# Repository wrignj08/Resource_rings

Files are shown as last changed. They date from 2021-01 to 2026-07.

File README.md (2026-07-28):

# Resource_rings
This was a weekend project to display my computers (Ubuntu 20.04) CPU, RAM and GPU (NVIDIA) utilisation and temps on an external display, all the code and design files are available.
The project is powered by a Teensy 4.0 and uses four Addressable LED Ring - 16 Bit WS2812 RGB LED modules.
The display is designed to be mounted on the underside of a KOGAN 34" WQHD CURVED 21:9 ULTRAWIDE monitor.

You can check out the design and download the CAD at the link below
https://cad.onshape.com/documents/9b6b9370298a401bef62185d/w/3fc23328799e8dd97975f60a/e/fd6b8e9bd227a1a2b682e71e

The code on the Teensy is an Arduino sketch, the code on the PC is Python.

The Python side is managed with [uv](https://docs.astral.sh/uv/). Run `uv sync` to create the venv, then `./Run_rings.sh` to start the sender.

<p align="center">
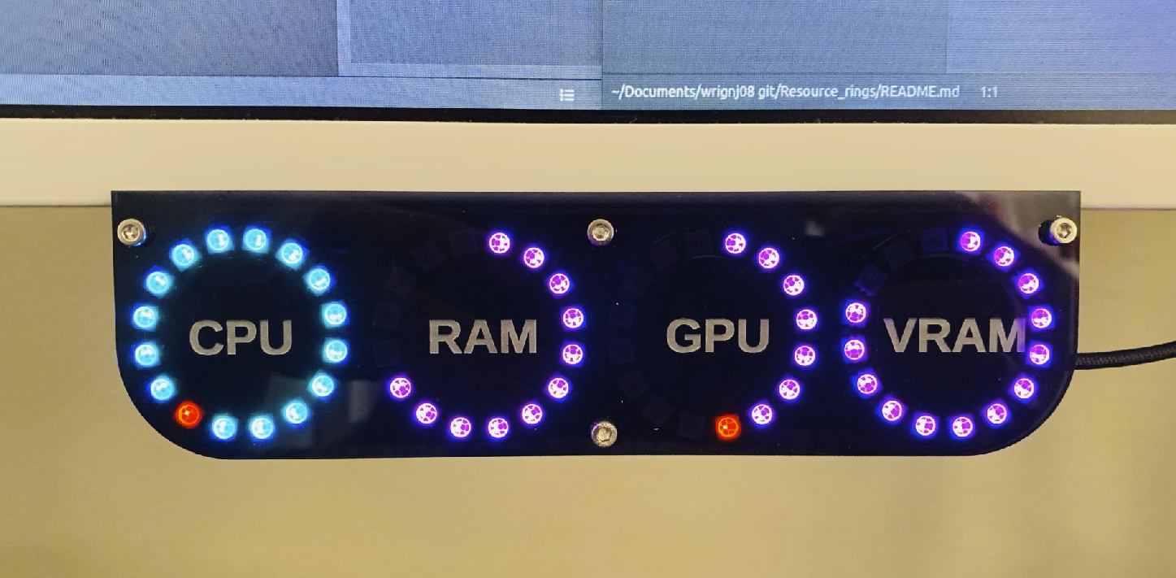
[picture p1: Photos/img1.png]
  
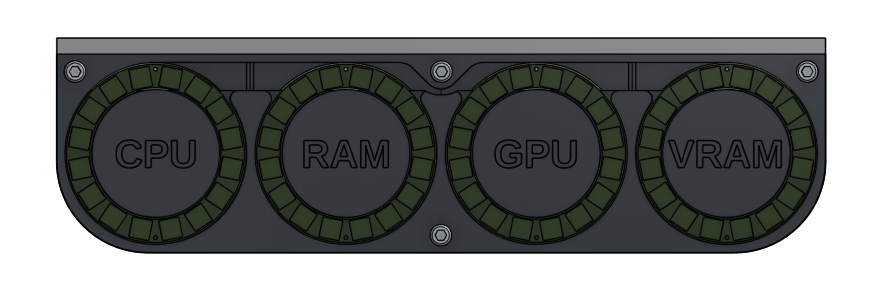
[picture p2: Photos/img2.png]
  
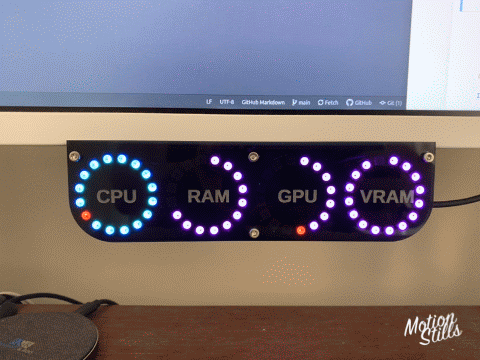
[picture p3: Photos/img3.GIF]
  
</p>

Features:<br>
CPU usage max core, purple on dial 1<br>
CPU usage max core last reading, green on dial 1<br>
CPU usage all core mean, teal on dial 1 overprints max core<br>
CPU temp, red on dial 1<br>
RAM usage, purple on dial 2<br>
RAM usage last reading, green on dial 2<br>
GPU usage, purple on dial 3<br>
GPU usage last reading, green on dial 3<br>
GPU temp, red on dial 3<br>
VRAM usage, purple on dial 4<br>
VRAM usage last reading, green dial 4<br>

Hardware:<br>
1 x Teensy 4.0 (probibly overkill but does a good job)<br>
https://core-electronics.com.au/teensy-4-0.html<br>
4 x Addressable LED Ring - 16 Bit WS2812 RGB LED<br>
https://core-electronics.com.au/cjmcu-16-bit-ws2812-5050-rgb-led-built-in-full-color-driving-lights-circle-development-board.html<br>
6 x M3 stainless steel self tapping thread insert<br>
https://www.aliexpress.com/item/32889542737.html<br>
6 x M3 x 8mm bolts<br>
https://www.aliexpress.com/item/1005001975621423.html<br>
3D printed housing (3 files, PLA is fine)<br>
https://github.com/wrignj08/Resource_rings/tree/main/CAD/3D%20printed%20STL%20files<br>
Laser cut and engraved acrylic face plate<br>
https://github.com/wrignj08/Resource_rings/tree/main/CAD/Later%20cut%20acrylic<br>

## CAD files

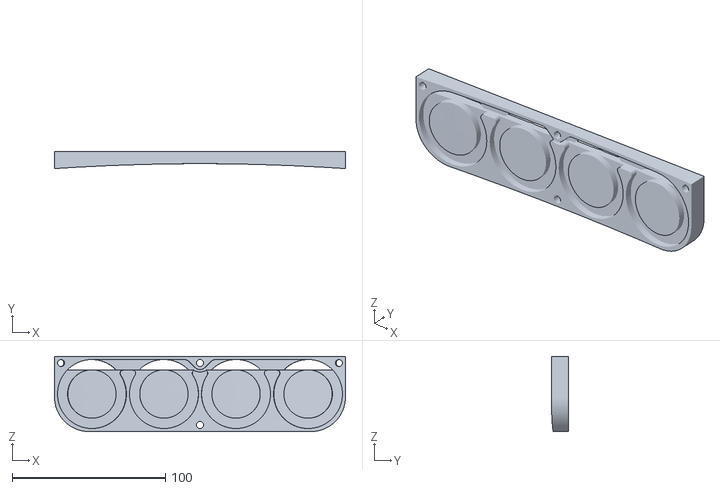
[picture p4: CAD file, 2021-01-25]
CAD/3D printed STL files/Monitor housing - Part 3.stl
189.9 x 11.2 x 49.0

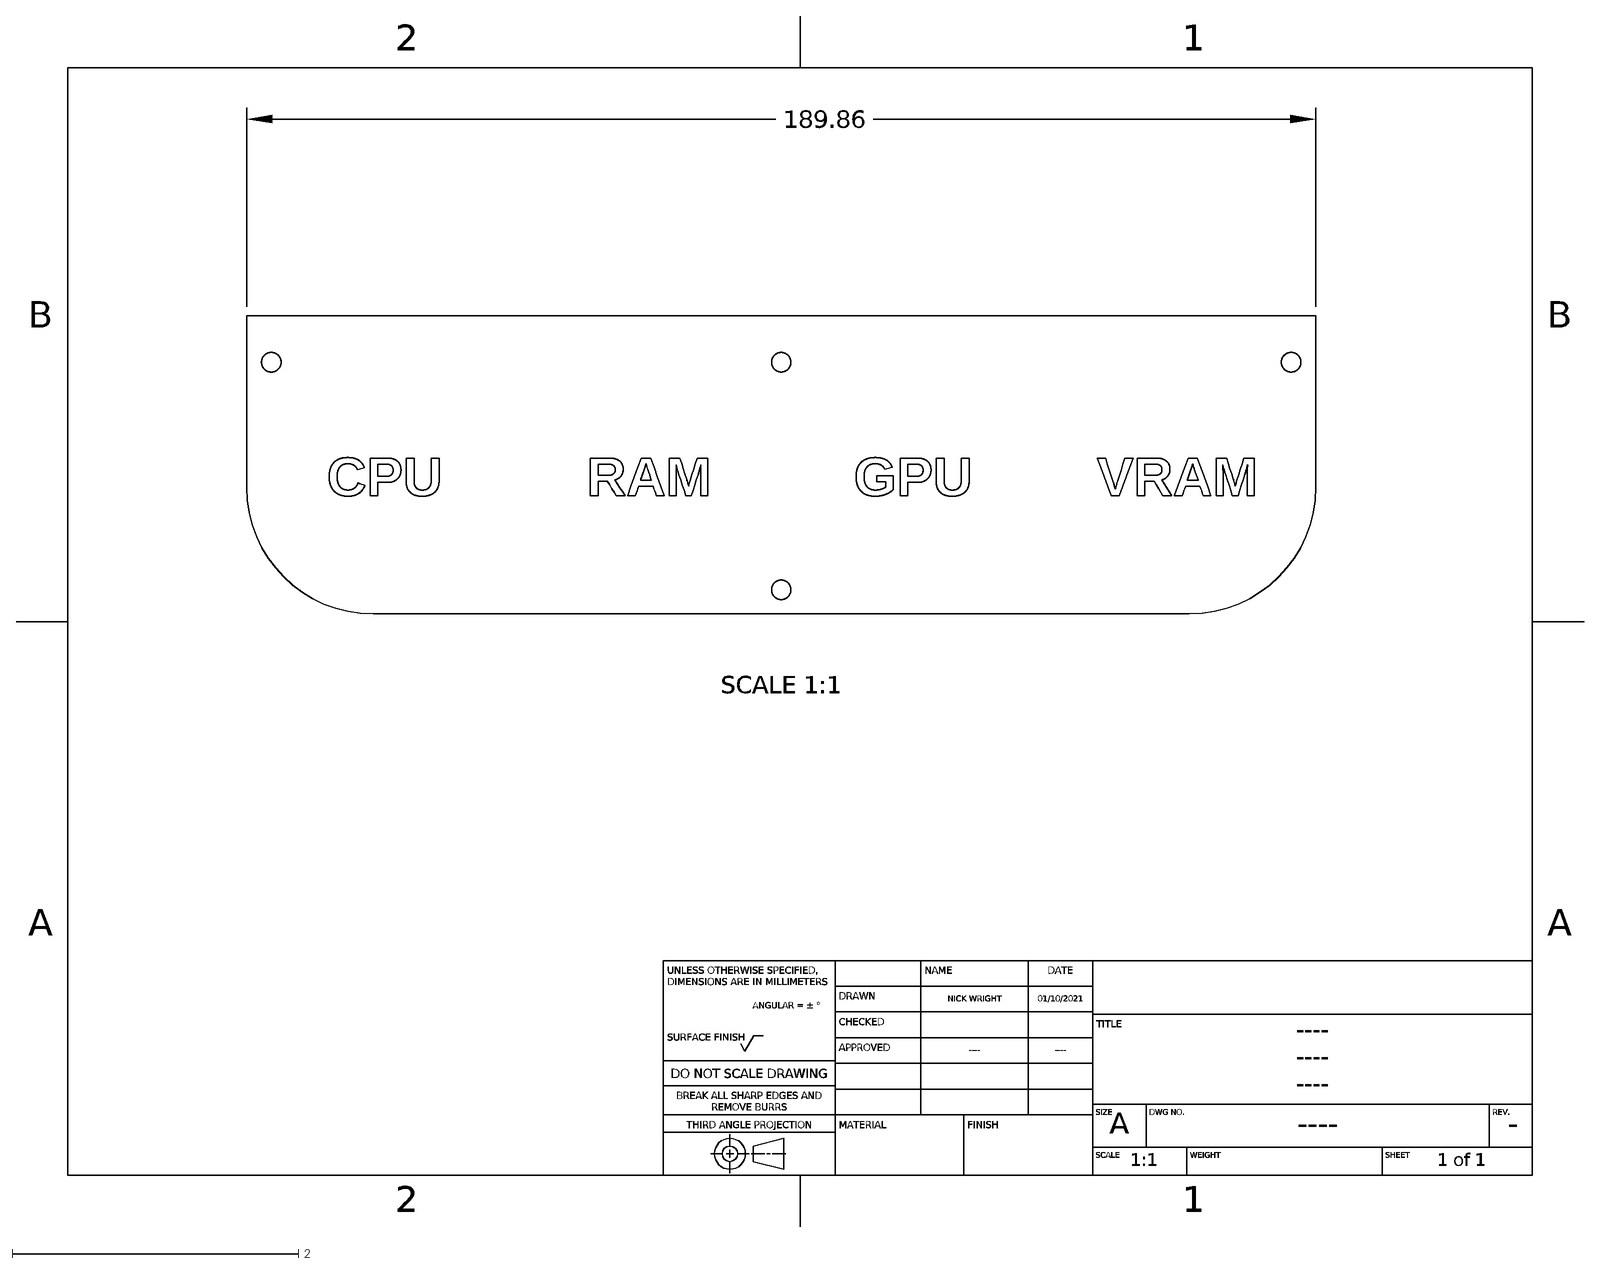
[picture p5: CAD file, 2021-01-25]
CAD/Later cut acrylic/Sketch 11 Drawing 1.dxf
2
1
A
B
UNLESS OTHERWISE SPECIFIED, DIMENSIONS ARE IN MILLIMETERS
ANGULAR = ± °
SURFACE FINISH
DO NOT SCALE DRAWING
BREAK ALL SHARP EDGES AND REMOVE BURRS
THIRD ANGLE PROJECTION
NAME
DATE
DRAWN
NICK WRIGHT
01/10/2021
CHECKED
APPROVED
----
MATERIAL
FINISH
TITLE
SIZE
DWG NO.
REV.
-
SCALE
1:1
WEIGHT
SHEET
1 of 1
SCALE 1:1
189.86

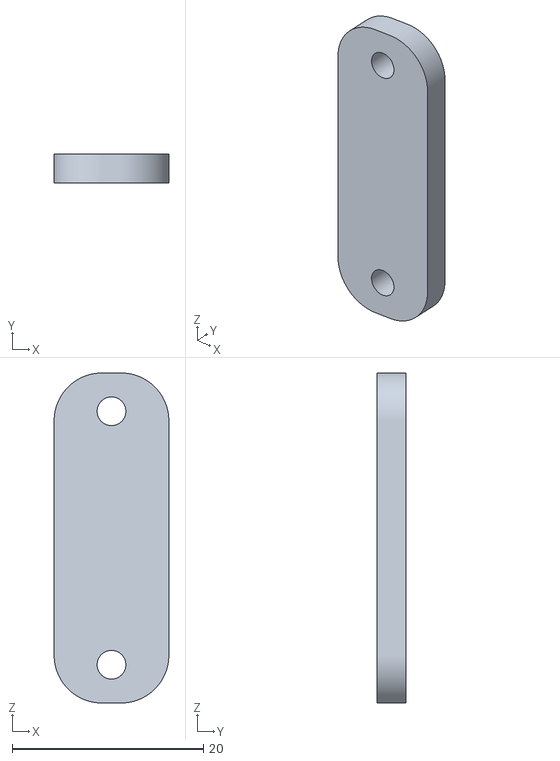
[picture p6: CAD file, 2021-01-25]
CAD/3D printed STL files/Monitor housing - Part 1.stl
12.0 x 3.00 x 34.5

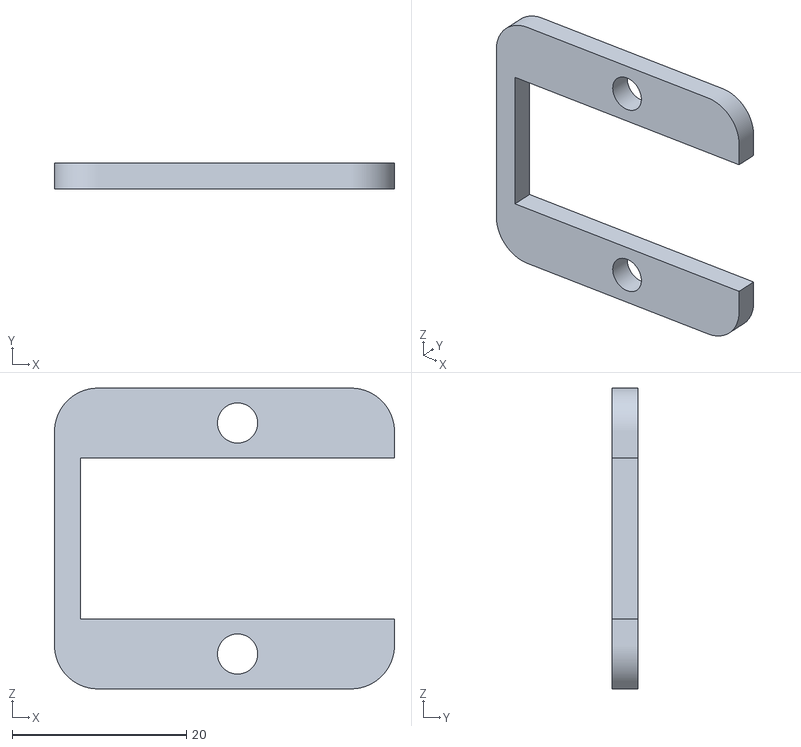
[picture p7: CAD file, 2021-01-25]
CAD/3D printed STL files/Monitor housing - Part 4.stl
39.0 x 3.00 x 34.5

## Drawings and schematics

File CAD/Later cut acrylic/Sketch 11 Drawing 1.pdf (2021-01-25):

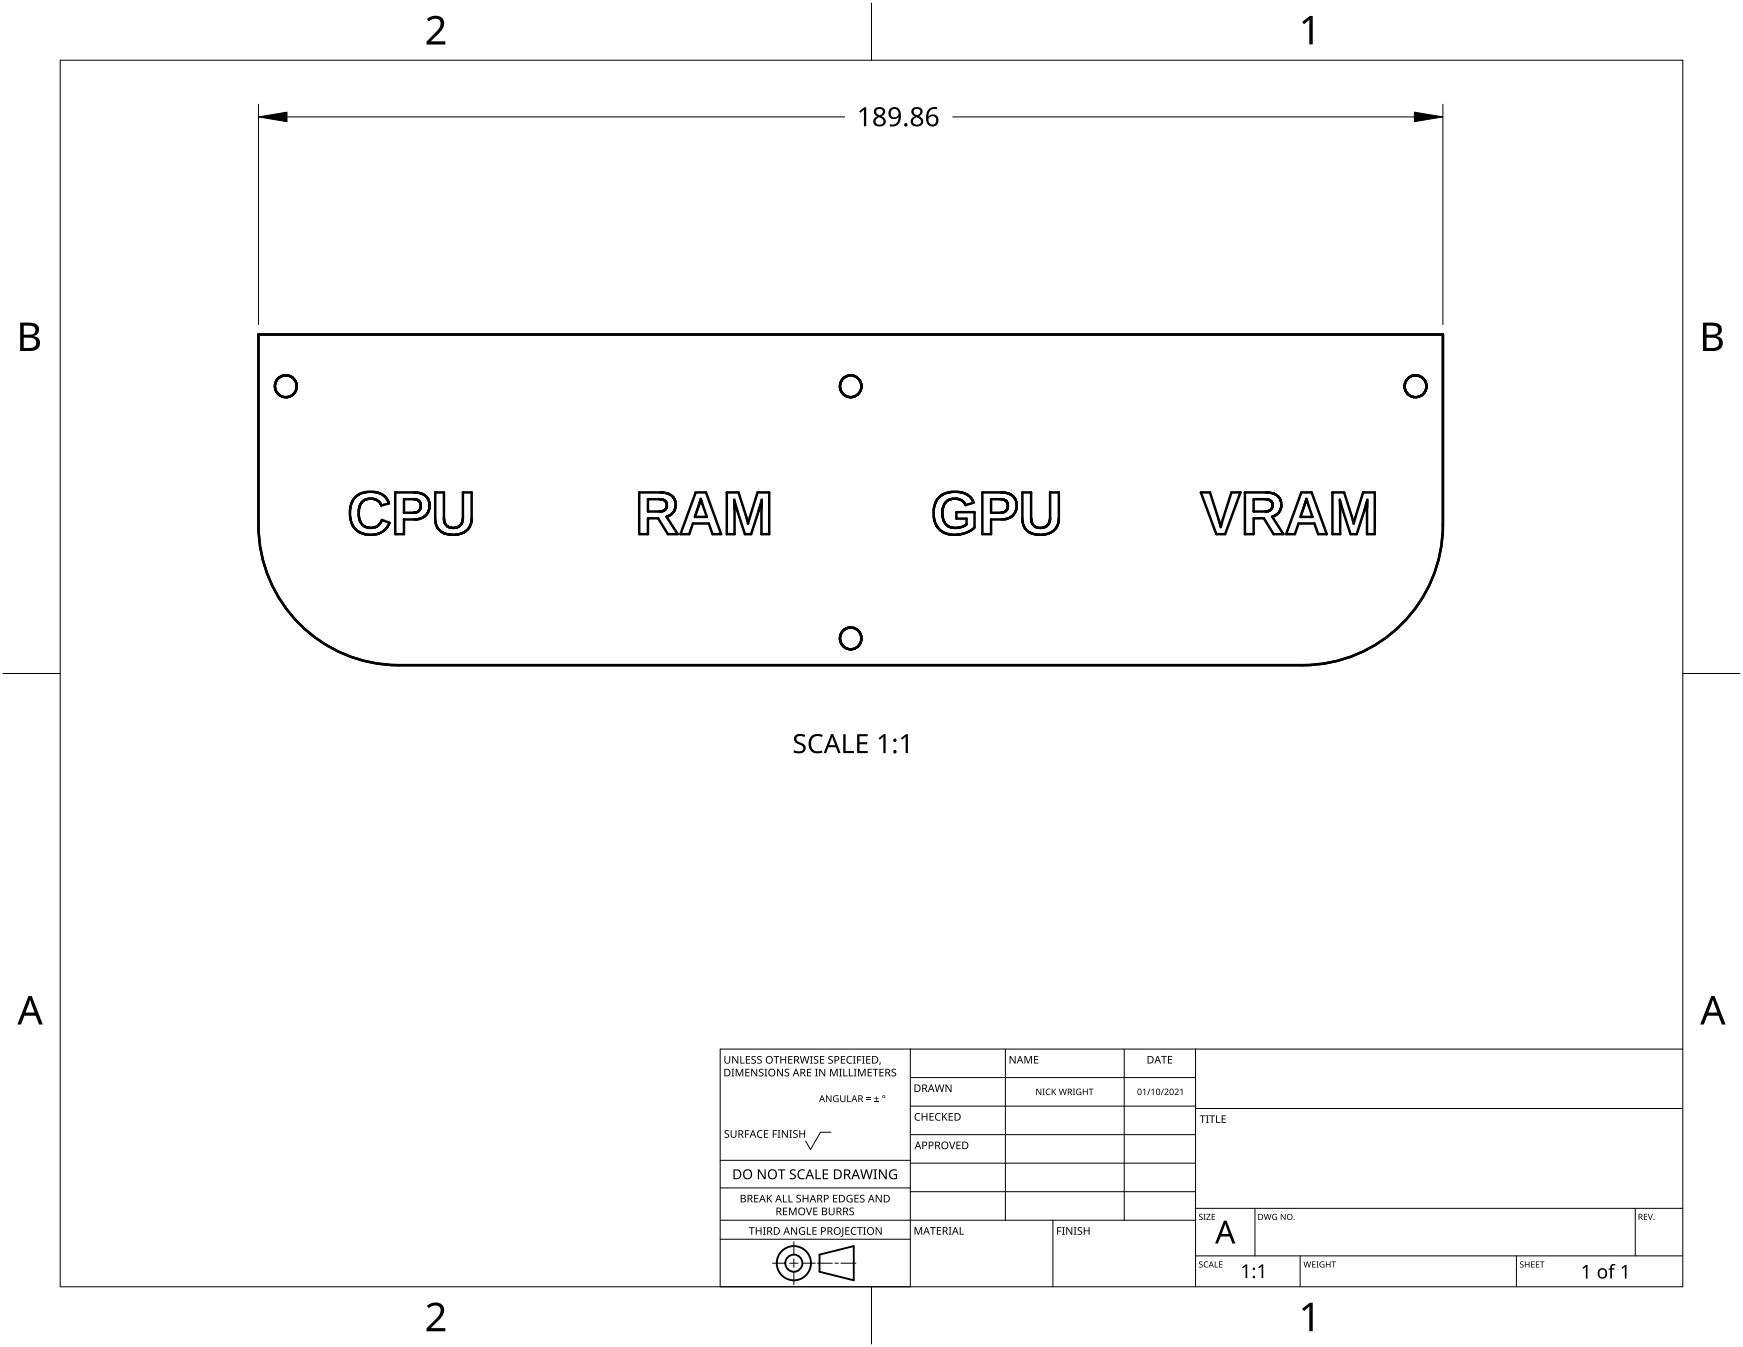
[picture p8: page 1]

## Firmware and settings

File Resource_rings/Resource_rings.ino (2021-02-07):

#include <FastLED.h>
#define NUM_LEDS_PER_STRIP 64
#define DATA_PIN 10
#define NUM_STRIPS 1
CRGB leds[NUM_LEDS_PER_STRIP * NUM_STRIPS];

const byte numChars = 32;
char receivedChars[numChars];
char tempChars[numChars];        // temporary array for use when parsing

// variables to hold the parsed data
char messageFromPC[numChars] = {0};

int max_CPU_core = 0;
int total_CPU = 0;
int CPU_temp = 0;
int RAM = 0;
int GPU_RAM = 0;
int GPU_util = 0;
int GPU_temp = 0;

int old_ano1 = 0;
int old_ano2 = 0;
int old_ano3 = 0;

int old_r1 = 0;
int old_r2 = 0;
int old_r3 = 0;
int old_r4 = 0;


unsigned long timer = millis();

int spinner[] = {15, 14, 13, 12, 11, 10, 9, 8, 7, 6, 5, 4, 28, 29, 30, 31, 16, 17, 18, 19, 43, 42, 41, 40, 39, 38, 37, 36, 60, 61, 62, 63, 48, 49, 50, 51, 52, 53, 54, 55, 56, 57, 58, 59, 35, 34, 33, 32, 47, 46, 45, 44, 20, 21, 22, 23, 24, 25, 26, 27, 3, 2, 1, 0};


boolean newData = false;

//============

void setup() {
  Serial.begin(9600);
  Serial.println("This demo expects 3 pieces of data - text, an integer and a floating point value");
  Serial.println("Enter data in this style <HelloWorld, 12, 24.7>  ");
  Serial.println();
  FastLED.setBrightness(10);
  FastLED.addLeds<NUM_STRIPS, WS2812, 10, GRB>(leds, NUM_LEDS_PER_STRIP);
  rev_ano();
}

//============
//https://forum.arduino.cc/index.php?topic=396450.0
void loop() {
  recvWithStartEndMarkers();
  if (newData == true) {
    strcpy(tempChars, receivedChars);
    // this temporary copy is necessary to protect the original data
    //   because strtok() used in parseData() replaces the commas with \0
    parseData();
    //      showParsedData();
    newData = false;
  }

  if (millis() - timer > 4000) {
    //    all_off();
    spiner_ano ();

  }

  delay(10);
  for (int led_num = max_CPU_core; led_num <= 16;) {
    leds[led_num].fadeToBlackBy( 1 );
    //    leds[led_num] = CRGB::Black;
    led_num++;
  }

}


void rev_ano() {
  for (int LED = 0; LED < 16; LED++) {

    leds[LED] = CRGB::White;
    leds[LED + 16] = CRGB::White;
    leds[LED + 32] = CRGB::White;
    leds[LED + 48] = CRGB::White;
    delay(40);
    FastLED.show();

  }
  for (int LED = 16; LED > -1; LED--) {

    leds[LED] = CRGB::Black;
    leds[LED + 16] = CRGB::Black;
    leds[LED + 32] = CRGB::Black;
    leds[LED + 48] = CRGB::Black;

    delay(40);
    FastLED.show();

  }
}

void spiner_ano () {
  for (int LED = 0; LED < 64; LED++) {
    leds[spinner[old_ano3]] = CRGB::Black;

    leds[spinner[old_ano2]] = CRGB::Red;
    leds[spinner[old_ano1]] = CRGB::HotPink;
    leds[spinner[LED]] = CRGB::White;

    old_ano3 = old_ano2;
    old_ano2 = old_ano1;
    old_ano1 = LED;

    delay(30);
    FastLED.show();

  }
}


void all_off() {
  for (int LED = 0; LED < NUM_LEDS_PER_STRIP; LED++) {

    leds[LED] = CRGB::Black;
    FastLED.show();
  }
}

//============

void recvWithStartEndMarkers() {
  static boolean recvInProgress = false;
  static byte ndx = 0;
  char startMarker = '<';
  char endMarker = '>';
  char rc;

  while (Serial.available() > 0 && newData == false) {
    rc = Serial.read();

    if (recvInProgress == true) {
      if (rc != endMarker) {
        receivedChars[ndx] = rc;
        ndx++;
        if (ndx >= numChars) {
          ndx = numChars - 1;
        }
      }
      else {
        receivedChars[ndx] = '\0'; // terminate the string
        recvInProgress = false;
        ndx = 0;
        newData = true;
      }
    }

    else if (rc == startMarker) {
      recvInProgress = true;
    }
  }
}

//============

//int RAM = 0;
//int GPU_ram = 0;
//int GPU_util = 0;

//incoming data looks like <max_CPU_core,total_CPU,RAM,GPU_util,GPU_ram>

void parseData() {      // split the data into its parts

  char * strtokIndx; // this is used by strtok() as an index

  strtokIndx = strtok(tempChars, ","); // this continues where the previous call left off
  max_CPU_core = atoi(strtokIndx);     // convert this part to an integer

  strtokIndx = strtok(NULL, ",");
  total_CPU = atoi(strtokIndx);

  strtokIndx = strtok(NULL, ",");
  RAM = atoi(strtokIndx);

  strtokIndx = strtok(NULL, ",");
  GPU_util = atoi(strtokIndx);

  strtokIndx = strtok(NULL, ",");
  GPU_RAM = atoi(strtokIndx);

  strtokIndx = strtok(NULL, ",");
  GPU_temp = atoi(strtokIndx);

  strtokIndx = strtok(NULL, ",");
  CPU_temp = atoi(strtokIndx);

  //green = 0x8AE729
  //purple = 0xe7298a
  //blue = 0x29E78A

  //set total CPU load (always lower than max CPU core)

  for (int led_num = 0; led_num < NUM_LEDS_PER_STRIP;) {
    if (led_num > total_CPU) {
      leds[led_num] = CRGB::Black;
    }
    if (led_num <= old_r1) {
      leds[led_num] = 0x8AE729;
    }
    if (led_num <= max_CPU_core) {
      leds[led_num] = 0xe7298a;
    }
    if (led_num <= total_CPU) {
      leds[led_num] = 0x29E78A;
    }
    leds[CPU_temp + 0] = 0xff0000;
    led_num++;
  }

  //set RAM
  for (int led_num = 16; led_num < NUM_LEDS_PER_STRIP;) {
    if (led_num > RAM + 16) {
      leds[led_num] = CRGB::Black;
    }
    if (led_num <= old_r2 + 16) {
      leds[led_num] = 0x8AE729;
    }
    if (led_num <= RAM + 16) {
      leds[led_num] = 0xe7298a;
    }

    led_num++;
  }

  //  //set GPU_util
  for (int led_num = 32; led_num < NUM_LEDS_PER_STRIP;) {
    if (led_num > GPU_util + 32) {
      leds[led_num] = CRGB::Black;
    }
    if (led_num <= old_r3 + 32) {
      leds[led_num] = 0x8AE729;
    }
    if (led_num <= GPU_util + 32) {
      leds[led_num] = 0xe7298a;
    }
    leds[GPU_temp + 32] = 0xff0000;
    led_num++;
  }

  //  //set off leds on ring 4
  for (int led_num = 48; led_num < NUM_LEDS_PER_STRIP;) {
    if (led_num > GPU_RAM + 48) {
      leds[led_num] = CRGB::Black;
    }
    if (led_num <= old_r4 + 48) {
      leds[led_num] = 0x8AE729;
    }
    if (led_num <= GPU_RAM + 48) {
      leds[led_num] = 0xe7298a;
    }

    led_num++;
  }

  FastLED.show();
  old_r1 = max_CPU_core;
  old_r2 = RAM;
  old_r3 = GPU_util;
  old_r4 = GPU_RAM;
  timer = millis();
}

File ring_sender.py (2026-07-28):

import subprocess as sp
import sys
import time
from typing import Callable, Dict, List, NamedTuple, Optional

import psutil
import serial
from serial.tools.list_ports import comports
from tqdm.auto import tqdm

# Constants
teensy_serial_id = "8434600"
leds_per_ring = 16
gpu_max_temperature = 100
gpu_min_temperature = 20
cpu_max_temperature = 100
cpu_min_temperature = 20

poll_interval = 0.4
reconnect_interval = 2.0
nvidia_smi_timeout = 2.0
nvidia_smi_retry_interval = 30.0
cpu_sensor_names = ("k10temp", "coretemp", "zenpower", "cpu_thermal", "acpitz")
cpu_sensor_labels = ("tctl", "tdie", "package id 0")

# Last known good value per metric, used when a source stops responding.
last_good_values: Dict[str, float] = {}
# Errors already reported, so a permanently broken source is not logged forever.
reported_errors: set = set()
# Time before which nvidia-smi should not be called again after a failure.
nvidia_smi_retry_after = 0.0


# Utility functions
def convert_output_to_list(output: bytes) -> List[str]:
    """
    Converts the output from bytes to list of strings.
    :param output: The output in bytes.
    :return: List of strings.
    """
    return output.decode("ascii").split("\n")[:-1]


def write(message: str) -> None:
    """
    Prints a message on the same stream as the progress bars, so it is not
    corrupted by them or lost to buffering.
    :param message: The message to print.
    """
    tqdm.write(message, file=sys.stderr)


def log_once(key: str, message: str) -> None:
    """
    Prints a message the first time a given failure is seen.
    :param key: Identifier for the failure.
    :param message: The message to print.
    """
    if key not in reported_errors:
        reported_errors.add(key)
        write(message)


def safe_metric(name: str, getter: Callable[[], float]) -> float:
    """
    Calls a metric getter, falling back to the last known good value (or 0) if it
    fails, so one dead source cannot stop the other rings.
    :param name: Name of the metric, used for caching and error reporting.
    :param getter: Callable returning the metric as a 0-1 fraction.
    :return: The metric clamped to 0-1.
    """
    try:
        value = getter()
        if value != value:  # NaN
            raise ValueError("metric returned NaN")
        value = min(1.0, max(0.0, float(value)))
        last_good_values[name] = value
        reported_errors.discard(name)
        return value
    except Exception as e:
        log_once(name, f"{name} unavailable ({type(e).__name__}: {e}), using fallback")
        return last_good_values.get(name, 0.0)


# GPU polling
class GpuStats(NamedTuple):
    temperature: Optional[float]
    memory_used: Optional[float]
    memory_total: Optional[float]
    utilization: Optional[float]


def parse_float(value: str) -> Optional[float]:
    """
    Parses a value from nvidia-smi, tolerating "N/A" and other junk.
    :param value: The raw field value.
    :return: The value as a float, or None if it is not numeric.
    """
    try:
        return float(value.strip().split()[0])
    except (ValueError, IndexError):
        return None


def get_gpu_stats() -> GpuStats:
    """
    Queries all GPU values in a single nvidia-smi call. Any failure (driver
    missing, timeout, unparsable output) yields empty stats rather than raising,
    and backs off so a broken driver is not probed every cycle.
    :return: The GPU stats, with None for any field that could not be read.
    """
    global nvidia_smi_retry_after

    if time.monotonic() < nvidia_smi_retry_after:
        return GpuStats(None, None, None, None)

    command = (
        "nvidia-smi --query-gpu=temperature.gpu,memory.used,memory.total,"
        "utilization.gpu --format=csv,noheader,nounits"
    )
    try:
        output = sp.check_output(
            command.split(), stderr=sp.DEVNULL, timeout=nvidia_smi_timeout
        )
    except Exception as e:
        nvidia_smi_retry_after = time.monotonic() + nvidia_smi_retry_interval
        log_once(
            "nvidia-smi",
            f"nvidia-smi unavailable ({type(e).__name__}: {e}), "
            f"retrying every {nvidia_smi_retry_interval:.0f}s",
        )
        return GpuStats(None, None, None, None)

    nvidia_smi_retry_after = 0.0
    reported_errors.discard("nvidia-smi")
    lines = convert_output_to_list(output)
    if not lines:
        return GpuStats(None, None, None, None)

    fields = lines[0].split(",")
    if len(fields) < 4:
        return GpuStats(None, None, None, None)

    return GpuStats(*(parse_float(field) for field in fields[:4]))


def get_gpu_temperature(stats: GpuStats) -> float:
    """
    Calculates the percentage of the max temperature that the current GPU
    temperature represents.
    :param stats: The GPU stats for this cycle.
    :return: The percentage of the max temperature.
    """
    if stats.temperature is None:
        raise ValueError("no GPU temperature reading")
    return (stats.temperature - gpu_min_temperature) / (
        gpu_max_temperature - gpu_min_temperature
    )


def get_gpu_memory_usage(stats: GpuStats) -> float:
    """
    Calculates the percentage of GPU memory that is currently used.
    :param stats: The GPU stats for this cycle.
    :return: The percentage of GPU memory that is currently used.
    """
    if stats.memory_used is None or not stats.memory_total:
        raise ValueError("no GPU memory reading")
    return stats.memory_used / stats.memory_total


def get_gpu_utilization(stats: GpuStats) -> float:
    """
    Gets the current GPU utilization.
    :param stats: The GPU stats for this cycle.
    :return: The current GPU utilization.
    """
    if stats.utilization is None:
        raise ValueError("no GPU utilization reading")
    return stats.utilization / 100


def get_ram_usage() -> float:
    """
    Gets the percentage of virtual memory that is currently used.
    :return: The percentage of virtual memory that is currently used.
    """
    ram_usage = psutil.virtual_memory().percent / 100
    return ram_usage


def get_total_cpu_usage() -> float:
    """
    Gets the percentage of CPU that is currently being used.
    :return: The percentage of CPU that is currently being used.
    """
    total_cpu_usage = psutil.cpu_percent(interval=0.1) / 100
    return total_cpu_usage


def get_max_cpu_core_usage() -> float:
    """
    Gets the maximum CPU core utilization.
    :return: The maximum CPU core utilization.
    """
    max_cpu_usage = max(psutil.cpu_percent(interval=0.1, percpu=True)) / 100.0  # type: ignore  # noqa: E501
    return max_cpu_usage
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

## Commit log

2021-01-25 added CAD and image
    [Monitor housing - Part 1.stl, Monitor housing - Part 3.stl, Monitor housing - Part 4.stl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]
2026-07-28 Make metric collection robust to API failures
    Each metric is now read through a wrapper that falls back to its last
    known good value if the source fails, so one dead source no longer stops
    the whole cycle and freezes every ring.
    - consolidate the three nvidia-smi calls into one, with a timeout and a
    30s backoff so a broken driver is not probed every cycle
    - hold the serial port open and reconnect on error instead of reopening
    it every loop
    - sleep while waiting for the teensy instead of busy-spinning a core
    - discover the CPU temp sensor rather than hardcoding k10temp index 1
    - print via tqdm.write so messages survive the progress bars
    - close the port and bars cleanly on Ctrl-C
    Co-Aut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
    [ring_sender.py]
2026-07-28 Switch from conda to uv
    - drop the conda env file and the leftover conda lines in Run_rings.sh
    - add pyproject.toml, .python-version and .gitignore for the uv setup
    - cd to the repo root in Run_rings.sh so the relative venv path works
    when the script is launched from elsewhere
    - note the uv sync step in the README
